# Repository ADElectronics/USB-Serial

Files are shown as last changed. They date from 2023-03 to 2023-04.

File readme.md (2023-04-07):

# USB-Serial Debug Tool

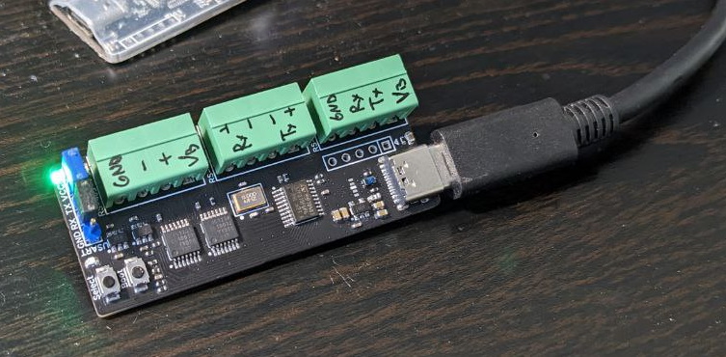
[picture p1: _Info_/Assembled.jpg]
PCB


Simple USB-Serial debug tool (work as VCP), can operate in one of selected by single button modes:
* USB to TTL (with build-in level converter, default IO level is 3.3V, but user can connect external VCCIO in range 1,4...3,6V)
* USB to RS-232 (only RX\TX)
* USB to RS-485
* USB to RS-422

MCU can be flash without external flasher\debugger by using internal bootloader, what is activated by pressing boot button before connecting device via USB.

**Hardware**

* MCU:               STM32F070F6P6 (can be replaced with STM32F042F6P6 wich have internal oscillator)
* Bus buffer:        SN74LVC125APWR
* Level converter:   SN74AVC1T45DBVR (can be replaced with SN74LVC1T45DBVR to extand VCCIO range to 1,65...5,5V)
* RS-232 driver:     ADM3101EACPZ (not nessesary, if you don't need RS-232)
* RS-485 driver:     ADM3485EARZ (can be replaced with TP75176E-FR or SIT3088ETK in DFN-8)
* RS-422 driver:     ADM3077EARZ (can be replaced with SP3490EN-L/TR)

**Firmware**

Makefile project, adapted to using with Visual Studio Code and J-Link Debugger.
Compilled with GCC (arm-none-eabi-gcc).
Based on generated project by STM32CubeMX and in firmware implimented simple bidirectional bridge:
USB <-> DMA <-> USART

User led on PCB is blinking when data was received from any serial interface (not USB).
User button is used to select next serial interface in circle (->USART->RS485->RS422->RS232->).

Simple test with band 1000000 show what all work fine, when sending one big string (command):
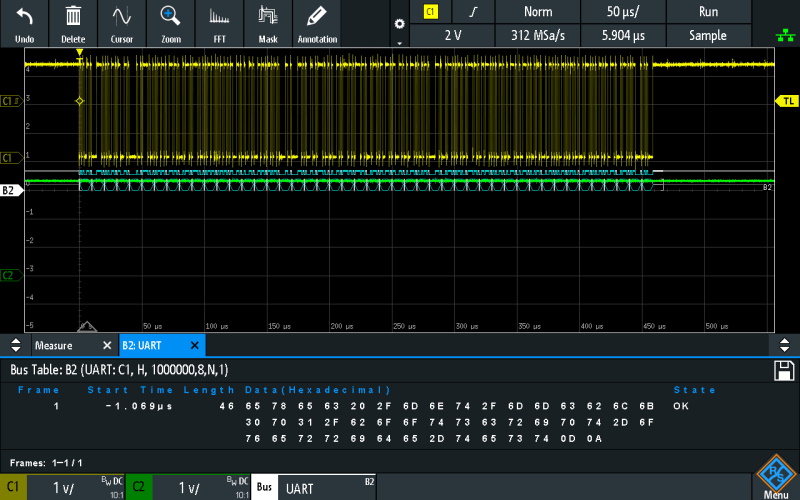
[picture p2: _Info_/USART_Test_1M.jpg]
USART


Issue with missed random bytes is observe, when used "Terminal v1.9b":
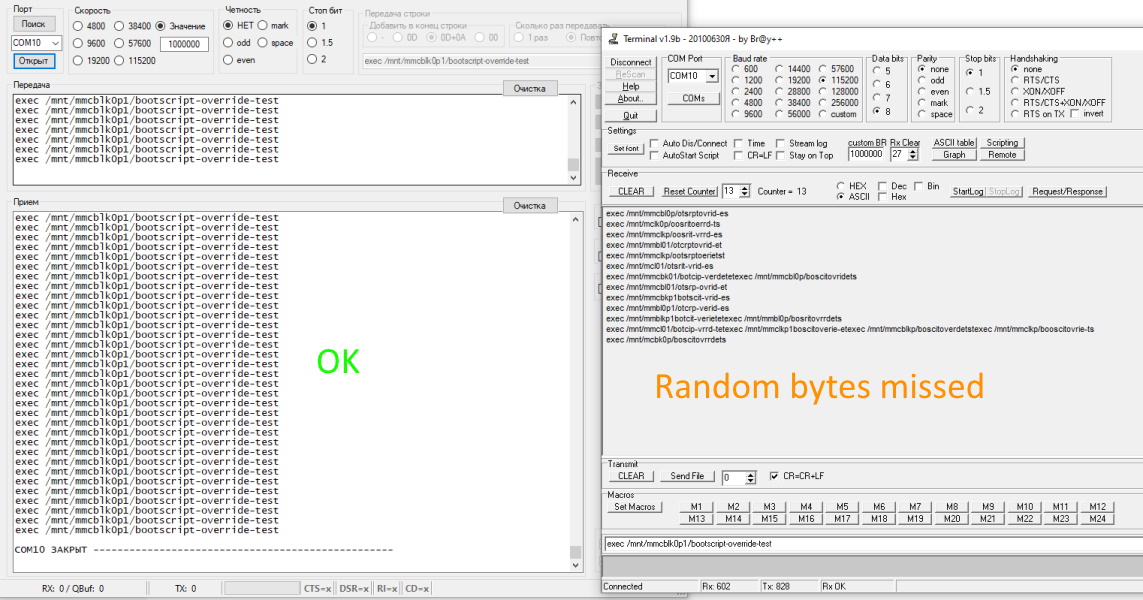
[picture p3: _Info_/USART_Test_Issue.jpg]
USART Issue


"Terminal v1.9b" is polling (both ways, RX and TX) COM port and when you send one string, this software send it one by one byte with not determined delay...
That's why VCP on STM32 can't work properly. If you use normal terminal software on PC - all works fine. :)

**Software**

WIP...

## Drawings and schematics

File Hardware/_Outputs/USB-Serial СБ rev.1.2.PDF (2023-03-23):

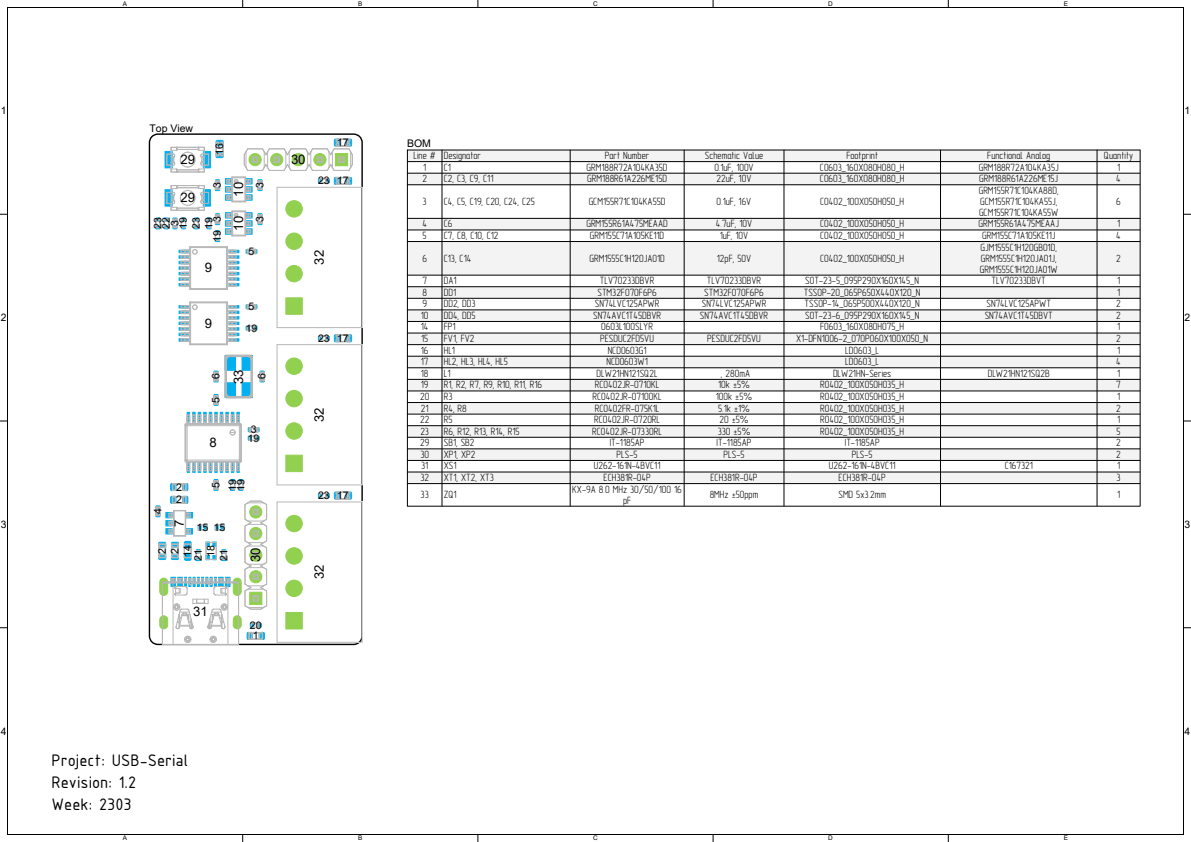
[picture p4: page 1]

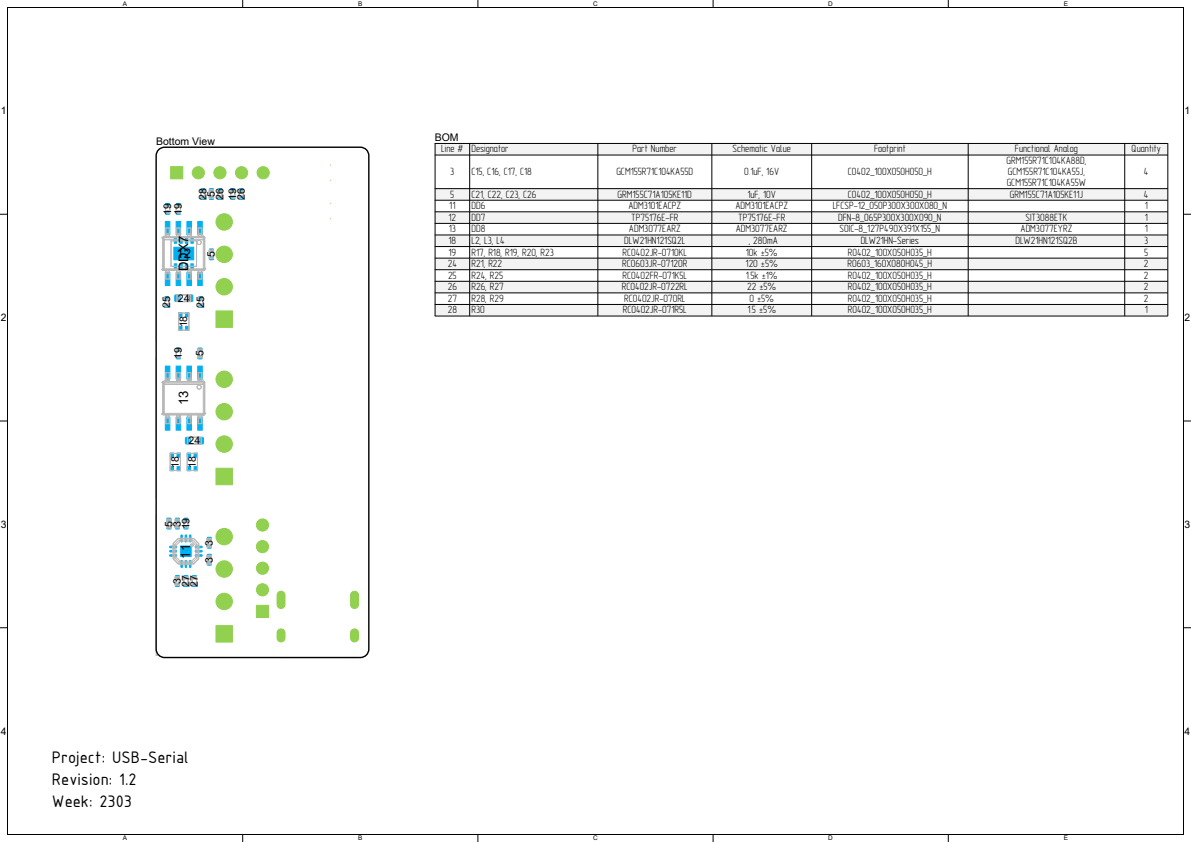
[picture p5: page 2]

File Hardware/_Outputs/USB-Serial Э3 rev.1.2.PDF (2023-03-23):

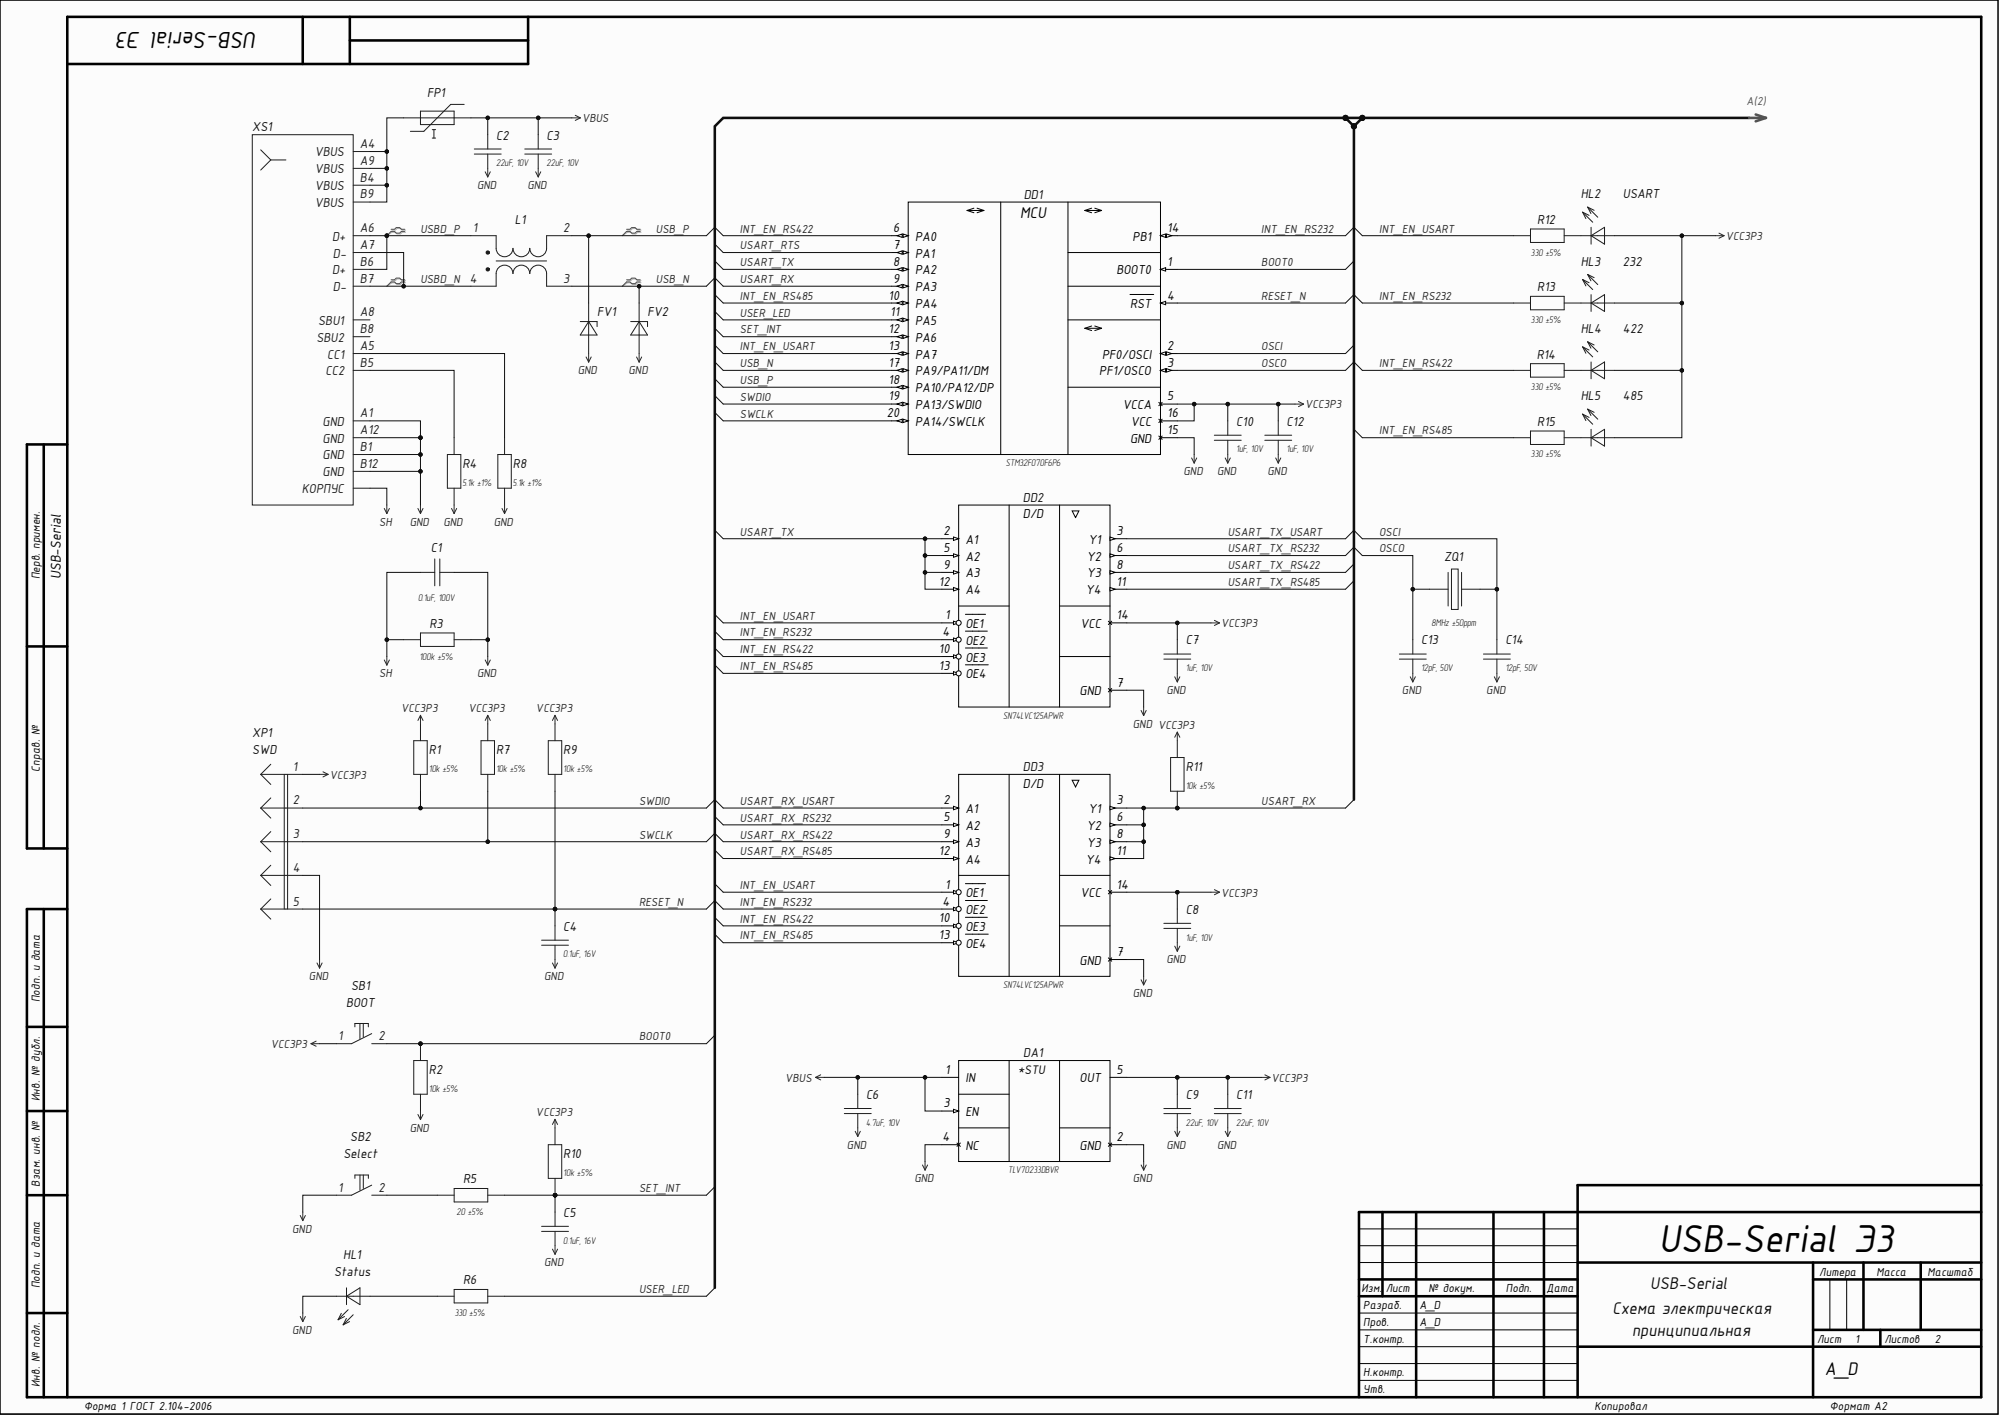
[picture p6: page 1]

Инв. № дубл. Подп. и да

Инв. № подл. Подп. и да

USB-Serial Схема электрическая принципиальная | Литера | Масса | Масштаб

Изм. Лист | № докум. | Подп. | Дата
Разраб. | A_D

Т.контр. | Лист 1 | Листов 2

Н.контр.
Утв.

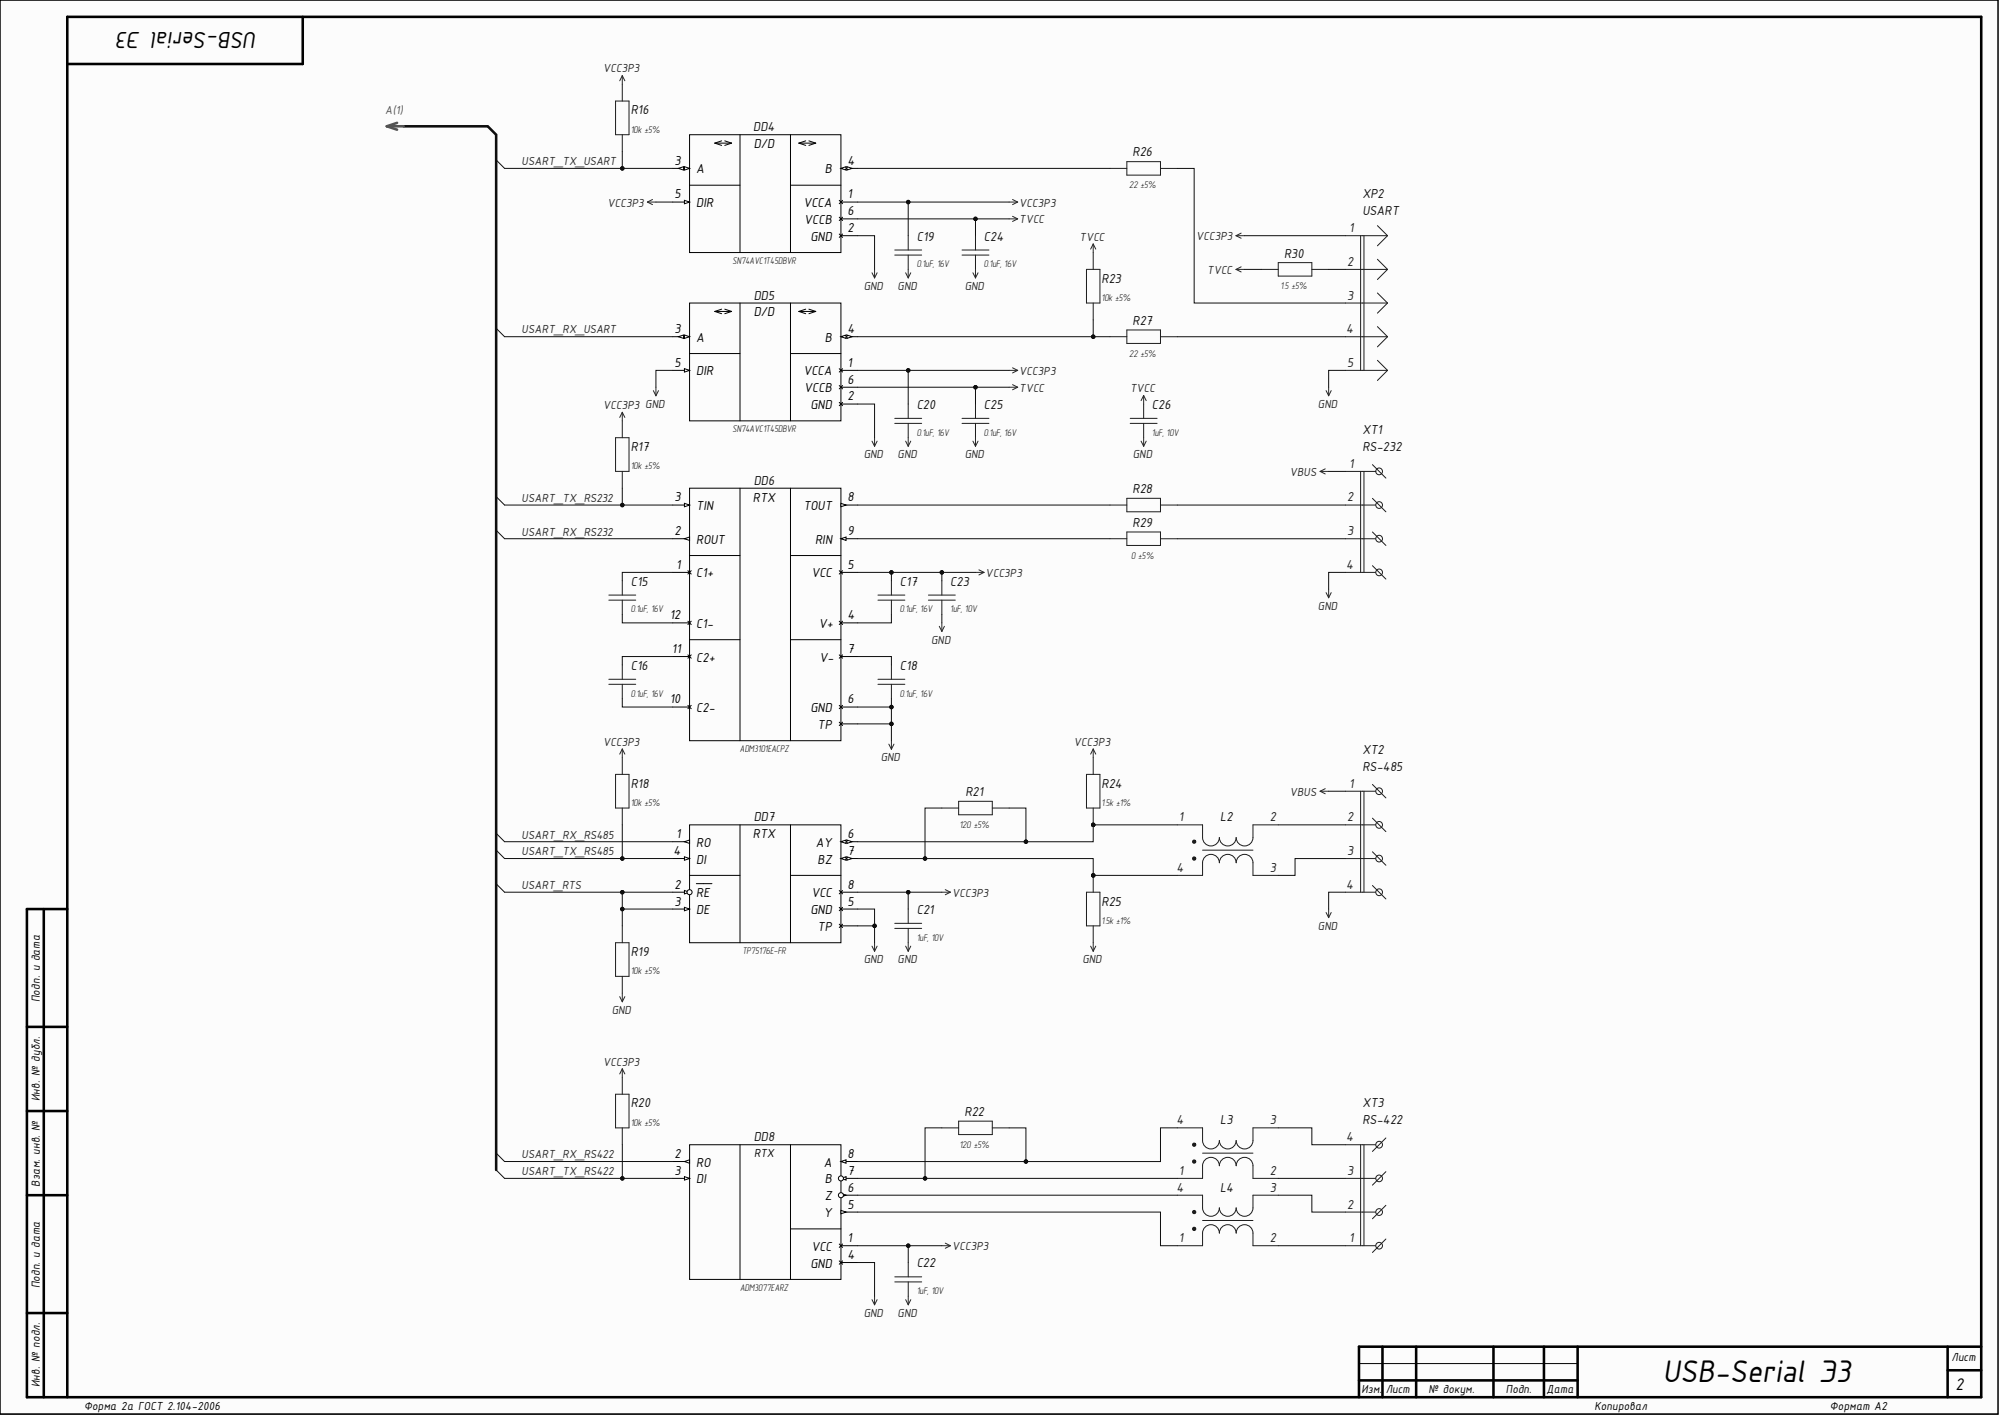
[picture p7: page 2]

RO 1 DI 4 | RTX | 3

Инв. № дубл. Подп. и да

Инв. № подл. Подп. и да

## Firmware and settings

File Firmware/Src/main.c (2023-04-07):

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
/* Includes ------------------------------------------------------------------*/
#include "main.h"
#include "usb_device.h"

/* USER CODE BEGIN Includes */
#include "usbd_cdc_if.h"
/* USER CODE END Includes */


void SystemClock_Config(void);
static void MX_GPIO_Init(void);
static void MX_DMA_Init(void);
static void MX_USART2_UART_Init(void);
/* USER CODE BEGIN 0 */
#define INTERFACE_RS232_ENABLE                  1

typedef enum
{
   INTRF_USART = 0,
   INTRF_RS485,
   INTRF_RS422,
#if(INTERFACE_RS232_ENABLE)
   INTRF_RS232
#endif
} interface_t;


static interface_t current_int = INTRF_USART;
//static uint8_t buf_tx[UART_BUF_LEN];
static uint8_t buf_rx[UART_BUF_LEN];

void NewDataReceived()
{
   uint32_t position_dma = LL_DMA_GetDataLength(DMA1, LL_DMA_CHANNEL_5);
   uint32_t data_len = UART_BUF_LEN - position_dma;

   if (data_len > 0 && data_len < UART_BUF_LEN)
   {
      LL_GPIO_SetOutputPin(GPIOA, LL_GPIO_PIN_5);
      CDC_Transmit_FS(&buf_rx[0], data_len);
   }

   LL_DMA_DisableChannel(DMA1, LL_DMA_CHANNEL_5);
   LL_DMA_SetDataLength(DMA1, LL_DMA_CHANNEL_5, UART_BUF_LEN);
   LL_DMA_EnableChannel(DMA1, LL_DMA_CHANNEL_5);
}

void NewDataTransmit(uint8_t *data, uint32_t len)
{
   LL_DMA_SetMemoryAddress(DMA1, LL_DMA_CHANNEL_4, (uint32_t)data);
   LL_DMA_SetDataLength(DMA1, LL_DMA_CHANNEL_4, len);
   LL_DMA_EnableChannel(DMA1, LL_DMA_CHANNEL_4);
}

void SetInterface(interface_t i)
{
   switch (i)
   {
      case INTRF_RS485:
         LL_GPIO_SetOutputPin(GPIOA, GPIO_PIN_0);
         LL_GPIO_SetOutputPin(GPIOA, GPIO_PIN_7);
         LL_GPIO_SetOutputPin(GPIOB, GPIO_PIN_1);
         LL_GPIO_ResetOutputPin(GPIOA, GPIO_PIN_4);
         LL_GPIO_SetPinMode(GPIOA, GPIO_PIN_1, LL_GPIO_MODE_ALTERNATE);
         break;

      case INTRF_RS422:
         LL_GPIO_SetOutputPin(GPIOA, GPIO_PIN_4);
         LL_GPIO_SetOutputPin(GPIOA, GPIO_PIN_7);
         LL_GPIO_SetOutputPin(GPIOB, GPIO_PIN_1);
         LL_GPIO_ResetOutputPin(GPIOA, GPIO_PIN_0);
         LL_GPIO_SetPinMode(GPIOA, GPIO_PIN_1, LL_GPIO_MODE_OUTPUT);
         LL_GPIO_ResetOutputPin(GPIOA, GPIO_PIN_1);
         break;

#if(INTERFACE_RS232_ENABLE)
      case INTRF_RS232:
         LL_GPIO_SetOutputPin(GPIOA, GPIO_PIN_0);
         LL_GPIO_SetOutputPin(GPIOA, GPIO_PIN_4);
         LL_GPIO_SetOutputPin(GPIOA, GPIO_PIN_7);
         LL_GPIO_ResetOutputPin(GPIOB, GPIO_PIN_1);
         LL_GPIO_SetPinMode(GPIOA, GPIO_PIN_1, LL_GPIO_MODE_OUTPUT);
         LL_GPIO_ResetOutputPin(GPIOA, GPIO_PIN_1);
         break;
#endif

      default: // INTRF_USART
         LL_GPIO_SetOutputPin(GPIOA, GPIO_PIN_0);
         LL_GPIO_SetOutputPin(GPIOA, GPIO_PIN_4);
         LL_GPIO_SetOutputPin(GPIOB, GPIO_PIN_1);
         LL_GPIO_ResetOutputPin(GPIOA, GPIO_PIN_7);
         LL_GPIO_SetPinMode(GPIOA, GPIO_PIN_1, LL_GPIO_MODE_OUTPUT);
         LL_GPIO_ResetOutputPin(GPIOA, GPIO_PIN_1);
         break;
   }
}

/* USER CODE END 0 */

/**
  * @brief  The application entry point.
  * @retval int
  */
int main(void)
{
  /* MCU Configuration--------------------------------------------------------*/

  /* Reset of all peripherals, Initializes the Flash interface and the Systick. */
  HAL_Init();

  /* Configure the system clock */
  SystemClock_Config();

  /* Initialize all configured peripherals */
  MX_GPIO_Init();
  MX_DMA_Init();
  MX_USART2_UART_Init();
  MX_USB_DEVICE_Init();
  /* USER CODE BEGIN 2 */
   SetInterface(current_int);

   // RX
   LL_DMA_ConfigAddresses(DMA1, LL_DMA_CHANNEL_5, (uint32_t)&(USART2->RDR), (uint32_t)&buf_rx, LL_DMA_DIRECTION_PERIPH_TO_MEMORY);
   LL_DMA_SetDataLength(DMA1, LL_DMA_CHANNEL_5, UART_BUF_LEN);
   LL_DMA_EnableChannel(DMA1, LL_DMA_CHANNEL_5);

   // TX
   LL_DMA_SetPeriphAddress(DMA1, LL_DMA_CHANNEL_4, (uint32_t)&USART2->TDR);
   LL_DMA_EnableIT_TC(DMA1, LL_DMA_CHANNEL_4);
   //LL_DMA_EnableChannel(DMA1, LL_DMA_CHANNEL_4);

   LL_USART_EnableDMAReq_RX(USART2);
   LL_USART_EnableDMAReq_TX(USART2);
   LL_USART_EnableIT_IDLE(USART2);
   LL_USART_Enable(USART2);
  /* USER CODE END 2 */

  /* Infinite loop */
  /* USER CODE BEGIN WHILE */
   for (;;)
   {
      if (LL_GPIO_IsInputPinSet(GPIOA, GPIO_PIN_6) == 0x00)
      {
         uint32_t count = 0;
         while (LL_GPIO_IsInputPinSet(GPIOA, GPIO_PIN_6) == 0x00)
         {
            HAL_Delay(1);
            count += 1;
         }

         if (count > 50)
         {
            current_int += 1;
#if(INTERFACE_RS232_ENABLE)
            if (current_int > INTRF_RS232)
#else
            if (current_int > INTRF_RS422)
#endif
            {
               current_int = INTRF_USART;
            }

            SetInterface(current_int);
            HAL_Delay(200);
         }
      }

      if (LL_GPIO_IsOutputPinSet(GPIOA, GPIO_PIN_5))
      {
         HAL_Delay(20);
         LL_GPIO_ResetOutputPin(GPIOA, GPIO_PIN_5);
      }
    /* USER CODE END WHILE */

    /* USER CODE BEGIN 3 */
   }
  /* USER CODE END 3 */
}

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


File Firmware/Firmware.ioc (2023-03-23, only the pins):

Mcu.UserName=STM32F070F6Px
PA0.Signal=GPIO_Output
PA1.Signal=USART2_DE
PA11.Signal=USB_DM
PA12.Signal=USB_DP
PA13.Signal=SYS_SWDIO
PA14.Signal=SYS_SWCLK
PA2.Signal=USART2_TX
PA3.Signal=USART2_RX
PA4.Signal=GPIO_Output
PA5.Signal=GPIO_Output
PA6.Signal=GPIO_Input
PA7.Signal=GPIO_Output
PB1.Signal=GPIO_Output
PF0-OSC_IN.Signal=RCC_OSC_IN
PF1-OSC_OUT.Signal=RCC_OSC_OUT

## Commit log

2022-10-12 hw v1.0
    [01_MCU.SchDoc, 02_IO.SchDoc, _USB-Serial.PrjPCB]
2022-10-14 fw fix de rx485 issue, HW v1.1 release
    [01_MCU.SchDoc, 02_IO.SchDoc, _USB-Serial.PrjPCB]
2023-03-23 hw v1.2
    [01_MCU.SchDoc, _USB-Serial.PrjPCB]
